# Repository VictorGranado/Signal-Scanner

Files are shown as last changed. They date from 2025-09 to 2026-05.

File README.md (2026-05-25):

# **Signal Scanner v1.0**

A multifunction handheld diagnostic and signal analysis tool for wireless scanning, RF detection, and basic electrical/electricmagnectic measurements.

---

## **Project Overview**

The **Signal Scanner v1.0** is a comprehensive diagnostic instrument built around the **ESP32-WROOM-DA** module.  
It combines **digital wireless analysis** (Wi-Fi, BLE, RF, EMF) with **electrical measurement capabilities** (Voltage, Current, Continuity, Frequency Counter) — all displayed through a dual-screen user interface.

Designed for **embedded developers, electronics hobbyists, and field engineers**, it provides a portable, menu-driven platform for analyzing and visualizing multiple signal domains in real time.

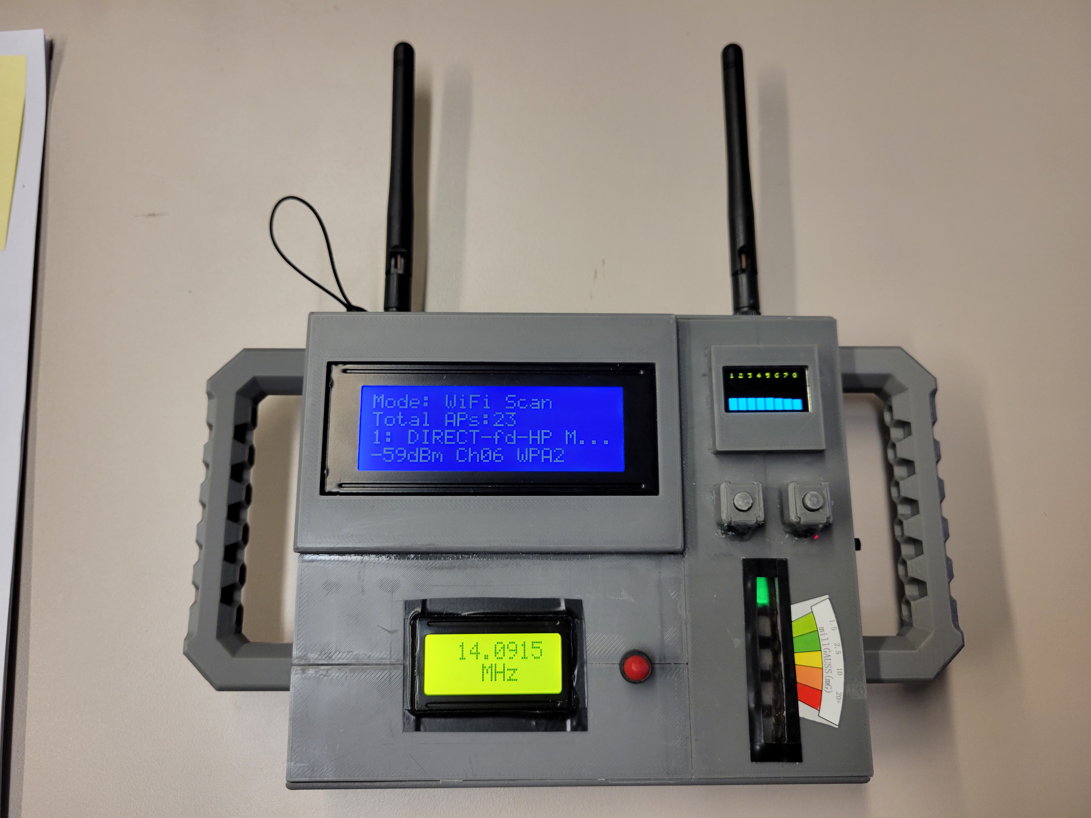
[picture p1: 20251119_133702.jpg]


---

## **Features**

### **1. Wi-Fi Scanner**
Scans for nearby wireless access points.  
**LCD:** displays SSID, RSSI (signal strength), channel, and encryption type.  
**OLED:** bar graph representation of the top RSSI values.

**Values:**
- **SSID:** network name  
- **RSSI:** signal strength in dBm (0 = strongest, −100 = weakest)  
- **CH:** Wi-Fi channel  
- **ENC:** encryption type (Open, WPA2, WPA3, etc.)

---

### **2. BLE Scanner**
Performs a passive BLE device scan using Kolban’s BLE library.  
**LCD:** shows device name (or MAC tail) and signal strength.  
**OLED:** bar graph of top device RSSI levels.

**Values:**
- **Device Name / MAC:** identifier  
- **RSSI (dBm):** received signal strength

---

### **3. Voltage Meter (0–25 V)**
Reads DC voltage via a voltage divider module and plots results on the OLED.  
**LCD:** shows wiring reference and live voltage reading.  
**OLED:** plots voltage (0–25 V) in real time.

**Connection:**
- **Probe+ → Voltage Divider Input**  
- **Probe− → GND**  
- **Divider output → GPIO34 (ADC1_CH6)**  

**Formula:**

Vin = Vadc × Divider Ratio

(Default: 5× module, optional 2× external divider)

---

### **4. Current Meter (ACS712-30A)**
Measures DC/AC current flow using the ACS712 Hall-effect sensor.  
**LCD:** shows wiring guide, live current, and plot status.  
**OLED:** real-time current graph (0–30 A scale).

**Connection:**
- **IP+ → Load supply input**  
- **IP− → Load output**  
- **Vout → ADC35 (ADC1_CH7)**  

**Calibration:**  
Long-press MODE in this mode to perform a **tare** (zero adjustment).

**Formula:**

I = (Vout - Voffset) / 0.066 (where 0.066 = 66 mV/A)

---

### **5. Continuity Tester**
Performs resistance-based continuity detection using a 10 kΩ pulldown reference.  
**LCD:** displays continuity status (“YES/NO”), resistance, and polarity note.  
**OLED:** shows an **animated connected wire** when continuity is detected or a **broken wire** when open.

**Connection:**
- **Red probe → GPIO25 (driven HIGH)**  
- **Black probe → GPIO32 (ADC1 input)**  
- **10 kΩ resistor → GPIO32 → GND**

**Logic:**

Rx = 10k × (3.3V - Vnode) / Vnode

Continuity = **YES** if Rx ≤ 600 Ω

---

### **6. RF Sniffer (AD8317)**
Measures relative RF power between 1 MHz–10 GHz using an AD8317 logarithmic detector.  
**LCD:** shows Vout voltage and equivalent dBm (calibrated or default).  
**OLED:** scrolling signal strength plot.

**Connection:**
- **AD8317 Vout → GPIO33 (ADC1_CH5)**  
- **Vcc:** 5 V  
- **GND:** common ground  
- **Antenna Input:** SMA connector (external antenna)

**Calibration:**
- **Long-press MODE** → capture P0 baseline (−90 dBm)  
- **Long-press SCROLL** → capture P1 reference (−30 dBm)

---

### **7. EMF Reader (Parallel)**
A parallel passive EMF detector monitors ambient electromagnetic activity.  
- Uses a **rectified antenna circuit** (antenna + diode + capacitor + amplifier).  
- Output is proportional to environmental EMF intensity.  
- **Display:** OLED bars or LED array (if connected).  

**Use Case:** detecting field sources (motors, transmitters, microwaves, etc.)

---

### **8. Frequency Counter (Parallel)**
Measures signal frequency via SMA or wired input.  
**LCD:** displays frequency in Hz/MHz.   
**Ideal for:** oscillators, PWM generators, communication signals.

**Connection:**
- **SMA Input:** strong RF or square-wave sources  
- **Wired Input:** logic-level test points  

---

## **Dynamic User Interface**

- **LCD (20×4)** — primary text interface: mode, wiring, and live values  
- **OLED (0.96″)** — graphical interface: signal bars, plots, or animation per mode  

**Controls:**
- **MODE (GPIO2):**  
  - Short press → change mode  
  - Long press (>1.2 s): special actions (tare, calibrate RF)
- **SCROLL (GPIO4):**  
  - Wi-Fi/BLE → scroll or auto-scroll lists  
  - Voltage/Current/RF → pause/resume plot  
  - RF → long press → capture calibration point

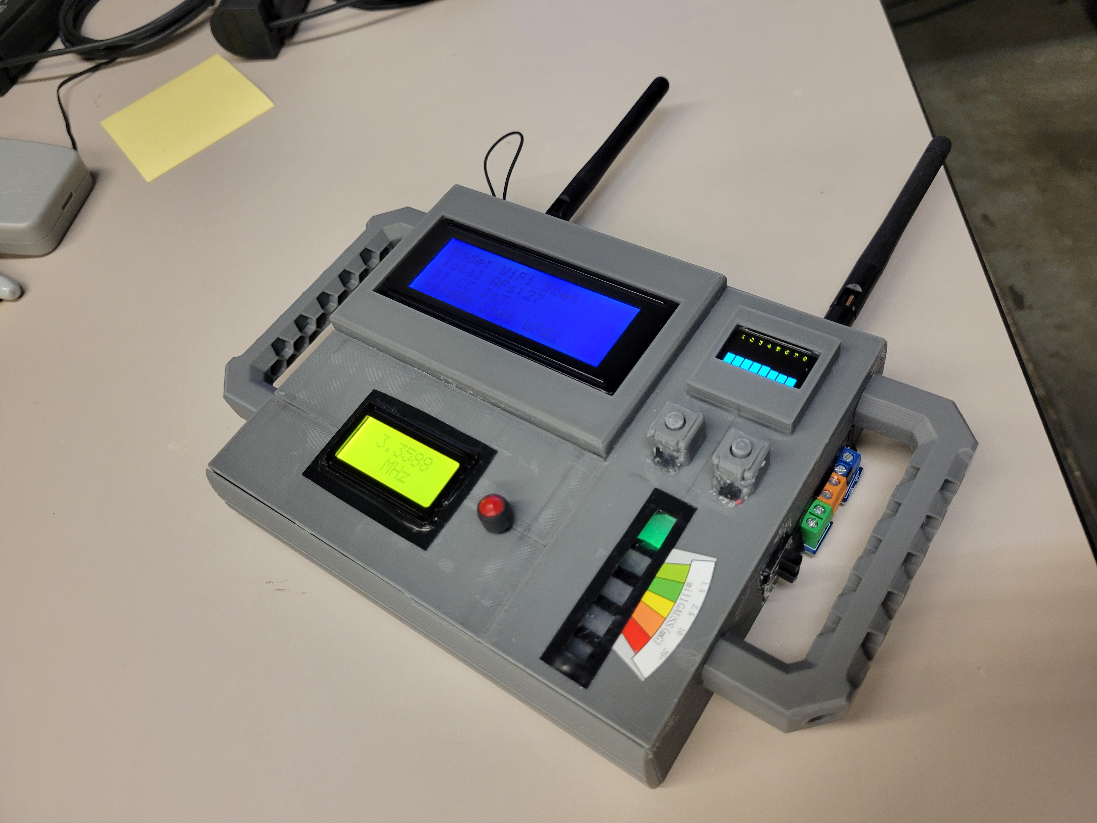
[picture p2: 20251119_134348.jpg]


---

## **System Specifications**

| Component | Function | Interface |
|---|---|---|
| ESP32-WROOM-DA | MCU + Wi-Fi + BLE + ADC | — |
| 20×4 LCD | Menu / Text | I²C (0x27) |
| 0.96″ OLED SSD1306 | Graphical plots | I²C (0x3C) |
| AD8317 | RF power detector (1 MHz–10 GHz) | Analog |
| ACS712-30A | Current sensing | Analog |
| Voltage Divider Module | Scales input to ADC range | Analog |
| Continuity Circuit | Resistance / continuity check | GPIO25 + ADC32 |
| EMF Detector | Field strength indication | Parallel |
| Frequency Counter | Pulse input (SMA / wired) | Parallel |
| Mode & Scroll Buttons | UI control | GPIO2, GPIO4 |
| Li-Ion Battery + Charger | Power source | — |

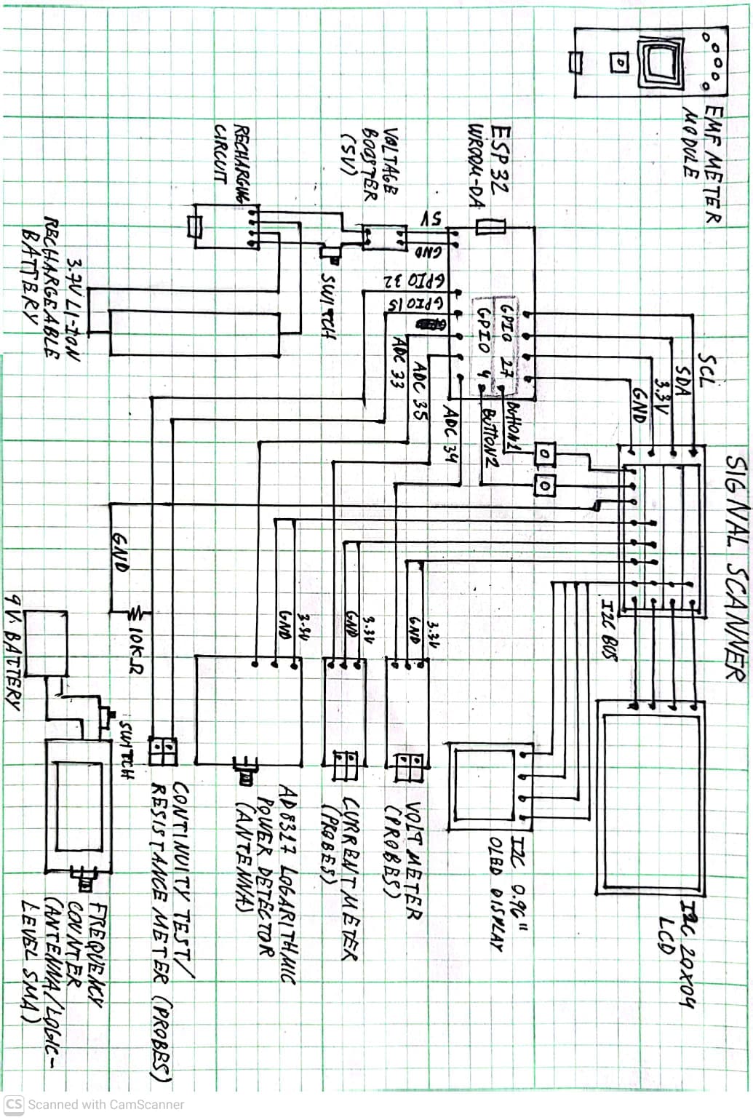
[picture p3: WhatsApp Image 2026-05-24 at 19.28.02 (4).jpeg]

---

## **Connection Configurations**

| Mode | Signal | ESP32 Pin | Notes |
|---|---|---|---|
| Voltage | Divider output | GPIO34 | Up to 25 V, 100k/100k divider |
| Current | ACS712 output | GPIO35 | 5 V module, 66 mV/A |
| Continuity | Probe+ = GPIO25, Probe− = GPIO32 | 10 kΩ pulldown to GND |
| RF Sniffer | AD8317 Vout | GPIO33 | 0.2–1.8 V typical |
| EMF Reader | Parallel analog | - | Relative measurement |
| Frequency Counter | SMA / wire input | - | Pulse input with limiter |

---

## **Setup and Usage**

1. Wire components according to the connection table.  
2. Install required Arduino libraries:  
   - `LiquidCrystal_I2C`  
   - `Adafruit_GFX`, `Adafruit_SSD1306`  
   - `WiFi`, `BLEDevice` (Kolban’s BLE)  
3. Open the main `.ino` file in Arduino IDE.  
4. Select **Partition Scheme → Huge APP**.  
5. Upload firmware to the ESP32.  
6. Power via USB or Li-Ion battery.  
7. Navigate using the MODE and SCROLL buttons.

---

## **Displayed Values and Their Meaning**

| Mode | Display Field | Meaning |
|---|---|---|
| Wi-Fi | SSID, RSSI, CH, ENC | Network information |
| BLE | Name/MAC, RSSI | Device info & signal strength |
| Voltage | Vin (V) | DC input voltage |
| Current | I (A) | Load current |
| Continuity | R (Ω), Continuity: YES/NO | Resistance or connection status |
| RF Sniffer | Vout (V), Power (dBm) | RF signal level |
| EMF | Bar level / LED | Field intensity |
| Frequency | f (Hz / MHz) | Signal frequency |

---

## **Test Plan and Results**

| Mode | Expected Behavior | Verified |
|---|---|---|
| Wi-Fi Scan | Detects SSIDs with correct RSSI and channels | ✅ |
| BLE Scan | Lists BLE devices with signal strength | ✅ |
| Voltage Meter | Reports accurate DC voltage after calibration | ✅ |
| Current Meter | Tare and dynamic response verified | ✅ |
| Continuity Tester | Detects shorts <600 Ω; OLED animation works | ✅ |
| RF Sniffer | Detects transmitters; relative dBm accurate | ✅ |
| EMF Reader | Responds to nearby EMF sources | ✅ |
| Frequency Counter | Stable frequency readings | ✅ |

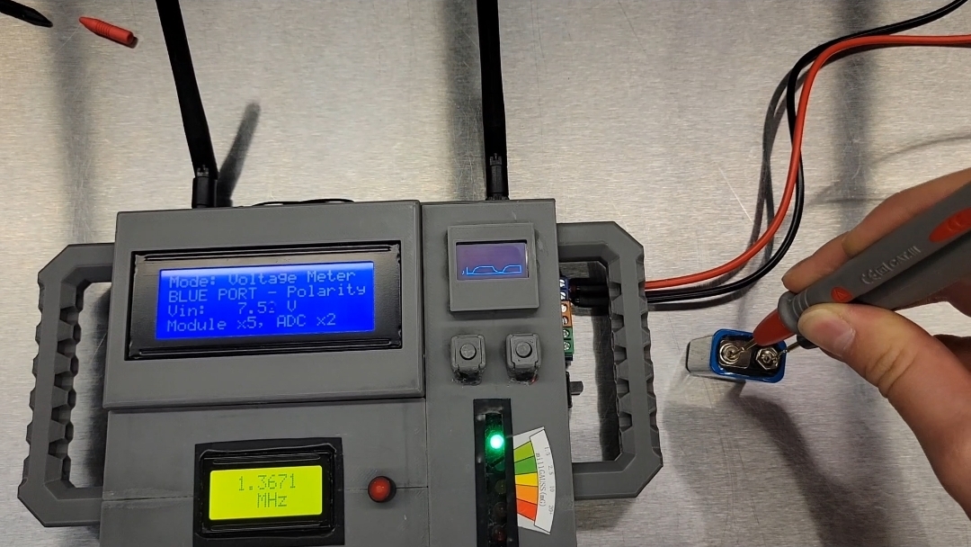
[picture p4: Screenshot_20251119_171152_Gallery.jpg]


---

## **Future Enhancements**

- SD card logging for data collection  
- Automatic range adjustment  
- RF sweep analyzer capability   

---

## **Updated Parts List**

| Component | Approx. Cost |
|---|---|
| ESP32-WROOM-DA | $5–10 |
| AD8317 RF Detector | $15–20 |
| ACS712-30A | $3–5 |
| Voltage Divider Module | $2–3 |
| Continuity Components | <$2 |
| EMF Detector Circuit | $14 |
| Frequency Counter (SMA Module) | $8–12 |
| 20×4 LCD | $5–10 |
| 0.96″ OLED SSD1306 | $2–5 |
| Buttons / Wiring | <$2 |
| Li-Ion Battery + Charger | $8–12 |
| **Total** | **~$70–100** |

---

## **Contributors**

**Victor Stafussi Granado** – Embedded Systems Design, Firmware Development, System Integration

---

## **License**

This project is licensed under the **MIT License**.  
See the LICENSE file for details.

---

## **Acknowledgments**

- AD8317 datasheet (Analog Devices)  
- ACS712, ESP32 ADC documentation  
- Arduino community libraries (Adafruit, Kolban, etc.)  
- EMF detector and frequency counter circuit references  
- Open-source hardware design resources

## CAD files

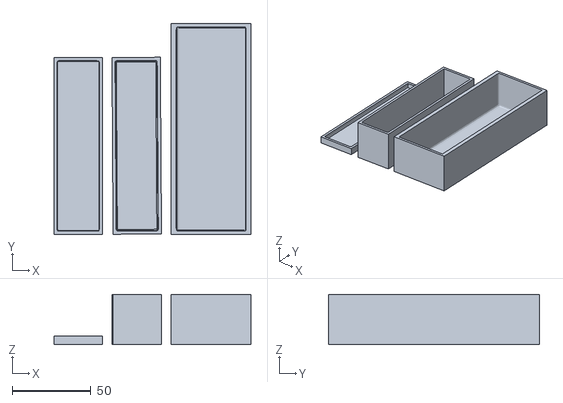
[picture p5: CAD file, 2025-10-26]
Signal Scanner disassembled part 3.stl
124.8 x 133.5 x 32.0

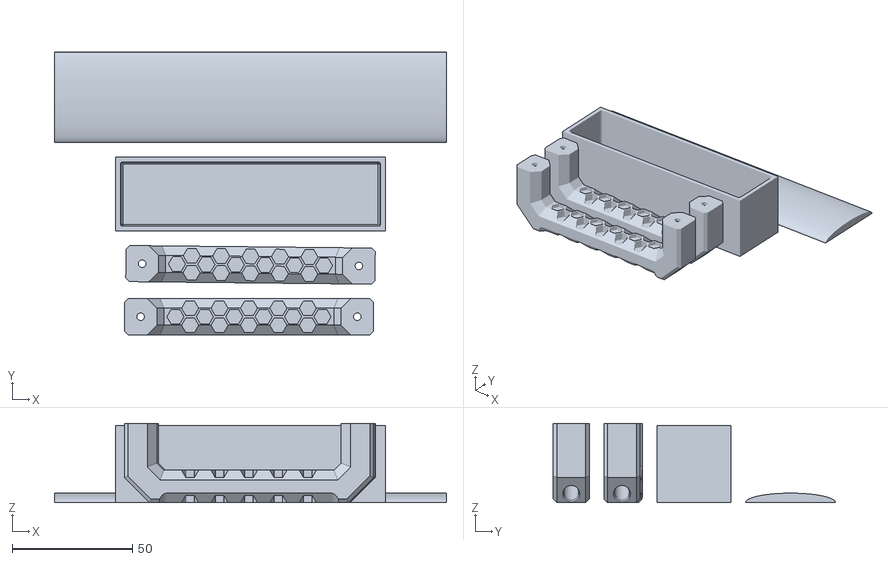
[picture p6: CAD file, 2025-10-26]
Signal Scanner disassembled part 4.stl
162.7 x 117.3 x 33.0

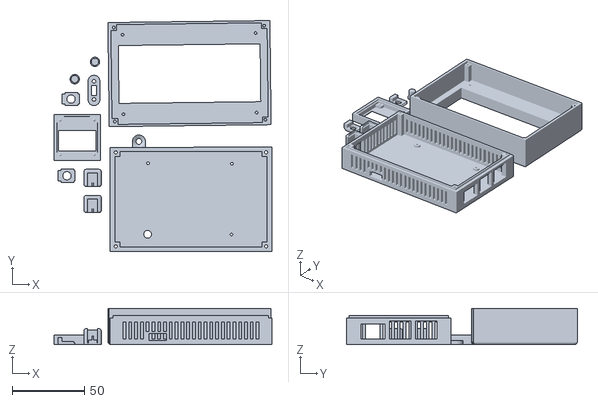
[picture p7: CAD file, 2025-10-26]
Signal Scanner disassembled part 1.stl
150.7 x 159.6 x 25.0

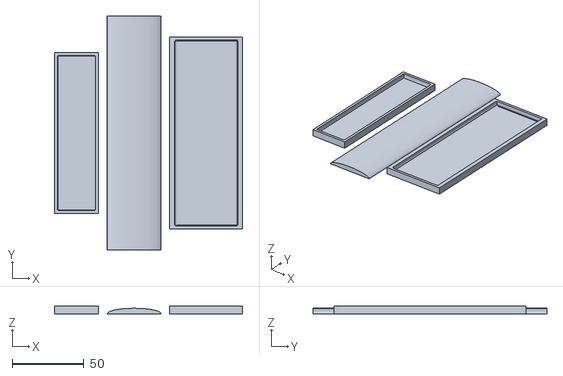
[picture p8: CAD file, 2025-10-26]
Signal Scanner disassembled part 2.stl
130.9 x 162.7 x 5.54

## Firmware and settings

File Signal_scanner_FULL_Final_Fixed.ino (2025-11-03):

// ================== Signal Scanner (ESP32-WROOM-DA) ==================
// Modes: Wi-Fi Scan + BLE Scan + Voltage Meter + Current Meter + Continuity + RF Sniffer (AD8317)
// ---------------------------------------------------------------------
// Hardware
//  - Buttons: MODE=GPIO2, SCROLL=GPIO4  (INPUT_PULLUP, LOW=pressed)
//  - LCD 20x4 I2C @ 0x27 (LiquidCrystal_I2C compatible fork recommended)
//  - OLED SSD1306 128x64 I2C @ 0x3C
//
// Voltage module (kit B08BZKPSFY):
//  - 0–25V module outputs ~Vin/5 (≈5 V at 25 V) -> add extra 2:1 divider to ESP32 ADC
//  - OUT -> 100k -> ADC34; ADC34 -> 100k -> GND  (overall x10 scale from ADC to Vin)
//
// Current module (ACS712-30A):
//  - Power at 5V, GND common with ESP32
//  - Route current IP+ (from supply) -> sensor -> IP- (to load)
//  - Vout -> 2:1 divider -> ADC35 (same 100k/100k idea)
//  - Sensitivity ≈ 66 mV/A, nominal mid ≈ 2.5 V at 0 A
//
// RF Sniffer (AD8317):
//  - Vout (0.2–1.8V typ) -> ADC33 (no divider)
//  - GND common, Vcc per module (~5V), antenna/probe on RF input
//
// Continuity (Option A):
//  - CONT_OUT=GPIO25 -> probe+, CONT_IN=GPIO26 -> probe- (ADC1), 10k pulldown to GND on CONT_IN
//
// Controls
//  - MODE (GPIO2):
//      * Short press: CHANGE MODE (WiFi → BLE → Volt → Curr → Cont → RF → …)
//      * Long press (>1.2s): in Current mode ONLY -> TARE (zero)
//      * Extra in RF mode: long press -> capture P0 baseline (-90 dBm)
//  - SCROLL (GPIO4):
//      * Wi-Fi/BLE: scroll list (hold to auto-scroll)
//      * Volt/Current/RF: pause/resume plot
//      * Extra in RF mode: long press -> capture P1 reference (-30 dBm)
//
// Splash:
//  - LCD: "Hello user", "Welcome to the Signal Scanner V1.0", "Initializing..."
//  - OLED: antenna with concentric waves animation
// ---------------------------------------------------------------------

#include <Arduino.h>
#include <Wire.h>
#include <LiquidCrystal_I2C.h>
#include <Adafruit_GFX.h>
#include <Adafruit_SSD1306.h>
#include <WiFi.h>

// BLE (Kolban)
#include <BLEDevice.h>
#include <BLEUtils.h>
#include <BLEScan.h>
#include <BLEAdvertisedDevice.h>

#include <vector>
#include <algorithm>
#include <math.h>

// ================= Pins =================
#define MODE_BUTTON_PIN    27
#define SCROLL_BUTTON_PIN  4
#define PIN_V_ADC          34    // ADC1_CH6 (Voltage)
#define PIN_I_ADC          35    // ADC1_CH7 (Current)
#define PIN_RF_ADC         33    // ADC1_CH5 (RF Vout)

// Continuity pins (Option A)
#define CONT_OUT           25    // drives 3.3V (probe +)
#define CONT_IN            32    // senses via ADC2_CH9 (probe -), external 10k pulldown to GND

// ================= LCD ==================
#define LCD_ADDR 0x27
#define LCD_COLS 20
#define LCD_ROWS 4
LiquidCrystal_I2C lcd(LCD_ADDR, LCD_COLS, LCD_ROWS);

// ================= OLED =================
#define OLED_RESET   -1
#define SCREEN_WIDTH 128
#define SCREEN_HEIGHT 64
Adafruit_SSD1306 oled(SCREEN_WIDTH, SCREEN_HEIGHT, &Wire, OLED_RESET);

// ================= Helpers =================
static String padOrTrim20(const String& s) {
  if (s.length() == 20) return s;
  if (s.length() < 20) { String t=s; while(t.length()<20) t+=' '; return t; }
  return s.substring(0,17) + "...";
}

static bool buttonEdge(uint8_t pin) {
  static uint32_t lastT[48] = {0};
  static uint8_t  lastS[48] = {HIGH};
  uint32_t now = millis();
  uint8_t s = digitalRead(pin);
  if (s != lastS[pin] && (now - lastT[pin]) > 30) {
    lastT[pin] = now;
    lastS[pin] = s;
    return (s == LOW);
  }
  return false;
}

static bool buttonHeld(uint8_t pin, uint32_t ms) {
  static uint32_t tDown[48] = {0};
  static uint8_t  wasDown[48] = {0};
  uint8_t s = (digitalRead(pin) == LOW);
  uint32_t now = millis();
  if (s && !wasDown[pin]) { wasDown[pin]=1; tDown[pin]=now; }
  else if (!s) { wasDown[pin]=0; return false; }
  if (wasDown[pin] && (now - tDown[pin] >= ms)) { return true; }
  return false;
}

// ================= Mode enum (use uint8_t to avoid proto issues) =================
enum ModeVals : uint8_t { WIFI_MODE=0, BLE_MODE, VOLT_MODE, CURR_MODE, CONT_MODE, RF_MODE, MODE_COUNT };
uint8_t currentMode = WIFI_MODE;

// forward declare
static void enterMode(uint8_t m);

// ===================== Wi-Fi Scanner =====================
struct APInfo { String ssid; int32_t rssi; int32_t channel; wifi_auth_mode_t enc; };
std::vector<APInfo> wifiAPs;
uint8_t wifiPage = 0;
uint32_t wifiHoldStart = 0, wifiLastScroll = 0;
const uint32_t scrollHoldTime = 500, scrollInterval = 500;

static const char* encToStr(wifi_auth_mode_t m) {
  switch (m) {
    case WIFI_AUTH_OPEN: return "OPEN";
    case WIFI_AUTH_WEP: return "WEP";
    case WIFI_AUTH_WPA_PSK: return "WPA";
    case WIFI_AUTH_WPA2_PSK: return "WPA2";
    case WIFI_AUTH_WPA_WPA2_PSK: return "WPA/WPA2";
    case WIFI_AUTH_WPA2_ENTERPRISE: return "WPA2-E";
    case WIFI_AUTH_WPA3_PSK: return "WPA3";
    case WIFI_AUTH_WPA2_WPA3_PSK: return "WPA2/3";
    default: return "?";
  }
}

static void oledBarsFromRSSI(const int *vals, int n, int nShow) {
  oled.clearDisplay(); oled.setTextSize(1); oled.setTextColor(SSD1306_WHITE);
  nShow = min(nShow, n);
  if (nShow <= 0) { oled.display(); return; }
  int w = SCREEN_WIDTH / nShow;
  int usableHeight = SCREEN_HEIGHT - 14;
  for (int i = 0; i < nShow; ++i) {
    int rssi = vals[i];
    rssi = max(-100, min(0, rssi));
    int bar = map(rssi, -100, 0, 0, usableHeight);
    int x = i * w;
    oled.setCursor(x + (w/2) - 3, 0); oled.print(i+1);
    oled.fillRect(x+1, SCREEN_HEIGHT - bar - 1, w - 3, bar, SSD1306_WHITE);
  }
  oled.display();
}

static void renderWiFiLCD(size_t idx) {
  lcd.setCursor(0,0); lcd.print(padOrTrim20("Mode: WiFi Scan"));
  char buf[21]; snprintf(buf,sizeof(buf),"Total APs:%-9d",(int)wifiAPs.size());
  lcd.setCursor(0,1); lcd.print(padOrTrim20(String(buf)));
  if (wifiAPs.empty()) {
    lcd.setCursor(0,2); lcd.print(padOrTrim20("No networks found"));
    lcd.setCursor(0,3); lcd.print(padOrTrim20(""));
    return;
  }
  const APInfo &a = wifiAPs[idx];
  String s1 = String(idx+1) + ": " + (a.ssid.length()?a.ssid:String("<hidden>"));
  lcd.setCursor(0,2); lcd.print(padOrTrim20(s1));
  snprintf(buf,sizeof(buf),"%ddBm Ch%02ld %s",(int)a.rssi,(long)a.channel,encToStr(a.enc));
  lcd.setCursor(0,3); lcd.print(padOrTrim20(String(buf)));
}

static void wifiScan() {
  lcd.clear(); renderWiFiLCD(0);
  WiFi.mode(WIFI_MODE_STA);
  WiFi.disconnect(true,true);
  delay(120);
  int n = WiFi.scanNetworks(false, true, false, 120);
  wifiAPs.clear();
  if (n > 0) {
    wifiAPs.reserve(n);
    for (int i=0;i<n;++i) {
      APInfo a; a.ssid=WiFi.SSID(i); a.rssi=WiFi.RSSI(i); a.channel=WiFi.channel(i); a.enc=WiFi.encryptionType(i);
      wifiAPs.push_back(a);
    }
    std::sort(wifiAPs.begin(), wifiAPs.end(), [](const APInfo&A,const APInfo&B){return A.rssi>B.rssi;});
    wifiPage=0; wifiHoldStart=wifiLastScroll=0;
  }
  renderWiFiLCD(wifiPage);
  const int maxBars = 8;
  int vals[maxBars]; int cnt = min((int)wifiAPs.size(), maxBars);
  for(int i=0;i<cnt;++i) vals[i]=wifiAPs[i].rssi;
  oledBarsFromRSSI(vals, cnt, cnt);
}

// ===================== BLE Scanner =====================
struct DevInfo { String name; String addr; int rssi; };
std::vector<DevInfo> bleDevs;
uint8_t blePage = 0;
uint32_t bleHoldStart = 0, bleLastScroll = 0;

int bleScanTime = 6;
BLEScan* pBLEScan = nullptr;

static String tailMac(const String& mac) {
  if (mac.length() >= 5) return mac.substring(mac.length()-5);
  return mac;
}

static void renderBLELCD(size_t idx) {
  lcd.setCursor(0,0); lcd.print(padOrTrim20("Mode: BLE Scan"));
  char buf[21]; snprintf(buf,sizeof(buf),"Total Dev:%-8d",(int)bleDevs.size());
  lcd.setCursor(0,1); lcd.print(padOrTrim20(String(buf)));
  if (bleDevs.empty()) {
    lcd.setCursor(0,2); lcd.print(padOrTrim20("No devices found"));
    lcd.setCursor(0,3); lcd.print(padOrTrim20(""));
    return;
  }
  const DevInfo &d = bleDevs[idx];
  String nm = d.name.length()? d.name : String("<noname>");
  String s1 = String(idx+1) + ": " + nm;
  lcd.setCursor(0,2); lcd.print(padOrTrim20(s1));
  snprintf(buf,sizeof(buf),"%ddBm %s",(int)d.rssi, tailMac(d.addr).c_str());
  lcd.setCursor(0,3); lcd.print(padOrTrim20(String(buf)));
}

static void oledBarsFromRSSI_BLE(const int *vals, int n, int nShow) {
  oled.clearDisplay(); oled.setTextSize(1); oled.setTextColor(SSD1306_WHITE);
  nShow = min(nShow, n);
  if (nShow <= 0) { oled.display(); return; }
  int w = SCREEN_WIDTH / nShow;
  int usableHeight = SCREEN_HEIGHT - 14;
  for (int i = 0; i < nShow; ++i) {
    int rssi = vals[i];
    rssi = max(-100, min(0, rssi));
    int bar = map(rssi, -100, 0, 0, usableHeight);
    int x = i * w;
    oled.setCursor(x + (w/2) - 3, 0); oled.print(i+1);
    oled.fillRect(x+1, SCREEN_HEIGHT - bar - 1, w - 3, bar, SSD1306_WHITE);
  }
  oled.display();
}

class MyAdvertisedDeviceCallbacks : public BLEAdvertisedDeviceCallbacks {
  void onResult(BLEAdvertisedDevice adv) override {
    DevInfo d;
    d.name = adv.haveName()? String(adv.getName().c_str()) : String("");
    d.addr = adv.getAddress().toString().c_str();
    d.rssi = adv.getRSSI();
    // upsert by MAC; keep strongest RSSI and latest name
    for (auto &x : bleDevs) {
      if (x.addr == d.addr) {
        if (d.rssi > x.rssi) x.rssi = d.rssi;
        if (d.name.length()) x.name = d.name;
        return;
      }
    }
    bleDevs.push_back(d);
  }
};

static void bleScan() {
  lcd.clear(); renderBLELCD(0);
  oled.clearDisplay(); oled.display();

  static bool inited=false;
  if (!inited) {
    BLEDevice::init("");
    pBLEScan = BLEDevice::getScan();
    pBLEScan->setAdvertisedDeviceCallbacks(new MyAdvertisedDeviceCallbacks(), true);
    pBLEScan->setActiveScan(true);
    pBLEScan->setInterval(100);
    pBLEScan->setWindow(99);
    inited = true;
  }
  bleDevs.clear();
  BLEScanResults* res = pBLEScan->start(bleScanTime, false);
  (void)res;
  std::sort(bleDevs.begin(), bleDevs.end(), [](const DevInfo&A,const DevInfo&B){return A.rssi>B.rssi;});
  blePage=0; bleHoldStart=bleLastScroll=0;
  renderBLELCD(blePage);
  const int maxBars=8; int vals[maxBars]; int cnt=min((int)bleDevs.size(), maxBars);
  for(int i=0;i<cnt;++i) vals[i]=bleDevs[i].rssi;
  oledBarsFromRSSI_BLE(vals, cnt, cnt);
  pBLEScan->clearResults();
}

// ===================== Voltage Meter =====================
static const float VREF_ADC        = 3.30f;   // with 11dB attenuation
static const float MODULE_RATIO    = 5.0f;    // 0–25V module: Vout ≈ Vin/5
static const float EXTRA_DIV       = 1.0f;    // set 2.0f if using extra 2:1 divider
static const float ADC_TO_VIN      = MODULE_RATIO * EXTRA_DIV; // overall scale
static const float V_FULL_SCALE    = 25.0f;   // plot top

static const int   ADC_SAMPLES_V   = 32;
static const float EMA_ALPHA_V     = 0.2f;
static float vTrace[SCREEN_WIDTH];
static bool  vPlotPaused = false;
static float emaV = 0.0f;

// ---- Two-point calibration (from your Fluke comparison) ----
// Vin_calibrated = CAL_GAIN_V * Vin_raw + CAL_OFFSET_V
static const float CAL_GAIN_V    = 1.032303f;
static const float CAL_OFFSET_V  = 0.470927f;   // volts


static int readADCavg(int pin, int n) { uint32_t acc=0; for(int i=0;i<n;++i) acc+=analogRead(pin); return (int)(acc/n); }
static float adcToVolts(int raw) { return (raw/4095.0f)*VREF_ADC; }

/*static float readVin() {
  int raw = readADCavg(PIN_V_ADC, ADC_SAMPLES_V);
  float vAdc = adcToVolts(raw);
  float vin  = vAdc * ADC_TO_VIN;
  if (vin < 0) vin = 0;
  return vin;
}*/

// Replace your readVin() with this calibrated version
static float readVin() {
  // Read averaged raw ADC and convert to volts at the ADC pin
  int   raw  = readADCavg(PIN_V_ADC, ADC_SAMPLES_V);
  float vAdc = adcToVolts(raw);          // volts at ADC pin (after any front-end divider)
  
  // Scale up by your divider/module ratio to get Vin (raw, uncalibrated)
  float vin_raw = vAdc * ADC_TO_VIN;

  // Apply 2-point calibration
  float vin_cal = (CAL_GAIN_V * vin_raw) + CAL_OFFSET_V;

  // Housekeeping
  if (vin_cal < 0)        vin_cal = 0;
  if (vin_cal > V_FULL_SCALE) vin_cal = V_FULL_SCALE;  // optional clamp for the plot

  return vin_cal;
}

//------------------------------------------------------------------------------------------------------------------------------------------------------

static void drawAxesVolt() {
  oled.clearDisplay(); oled.setTextColor(SSD1306_WHITE);
  const int gx=10, gy=6; const int gw=SCREEN_WIDTH-gx-2, gh=SCREEN_HEIGHT-gy-8;
  oled.drawRect(gx, gy, gw, gh, SSD1306_WHITE);
  oled.setTextSize(1);
  oled.setCursor(gx-22, gy-1); oled.print((int)V_FULL_SCALE); oled.print("V");
  oled.setCursor(gx-18, gy+gh-8); oled.print("0V");
  oled.display();
}

//-----------------------------------------------------------------------------------------------------------------------------------------------------
static void plotAddV(float v) { for(int i=0;i<SCREEN_WIDTH-1;++i) vTrace[i]=vTrace[i+1]; vTrace[SCREEN_WIDTH-1]=v; }

static void renderPlotV() {
  const int gx=10, gy=6; const int gw=SCREEN_WIDTH-gx-2, gh=SCREEN_HEIGHT-gy-8;
  oled.fillRect(gx+1, gy+1, gw-2, gh-2, SSD1306_BLACK);
  auto yFromV=[&](float v){ if(v<0)v=0; if(v>V_FULL_SCALE)v=V_FULL_SCALE;
    int y= gy+gh-2 - (int)round((v/V_FULL_SCALE)*(gh-3));
    if(y<gy+1)y=gy+1; if(y>gy+gh-2)y=gy+gh-2; return y; };
  int x0=gx+1, x1=gx+gw-2; int bufStart=SCREEN_WIDTH-(gw-2); if(bufStart<1) bufStart=1;
  int prevY=yFromV(vTrace[bufStart-1]);
  for(int x=x0; x<=x1; ++x){
    int idx=(x-x0)+bufStart; int y=yFromV(vTrace[idx]);
    oled.drawLine(x-1,prevY,x,y,SSD1306_WHITE); prevY=y;
  }
  oled.display();
}

static void renderLCDVolt(float vin) {
  lcd.setCursor(0,0); lcd.print(padOrTrim20("Mode: Voltage Meter"));
  lcd.setCursor(0,1); lcd.print(padOrTrim20("BLUE PORT - Polarity"));
  char buf[21]; snprintf(buf,sizeof(buf),"Vin: %6.2f V", vin);
  lcd.setCursor(0,2); lcd.print(padOrTrim20(String(buf)));
  String s4 = vPlotPaused ? String("Module x5, [PAUSE]") : String("Module x5, ADC x2 ");
  lcd.setCursor(0,3); lcd.print(padOrTrim20(s4));
}

// ===================== Current Meter (ACS712-30A) =====================
static const float DIV_RATIO_I     = 2.0f;     // 2:1 divider on ACS output
static const float ACS_VCC         = 5.00f;
static const float SENS_V_PER_A    = 0.066f;   // 66 mV/A
static const float I_FULL_SCALE    = 30.0f;

static const int   ADC_SAMPLES_I   = 32;
static const float EMA_ALPHA_I     = 0.2f;
static float iTrace[SCREEN_WIDTH];
static bool  iPlotPaused = false;
static float emaI = 0.0f;
static float tareZero_V = ACS_VCC*0.5f; // ~2.5 V nominal mid (sensor domain)

static float adcToSensorV_I(int raw) { float vAdc=adcToVolts(raw); return vAdc*DIV_RATIO_I; }
static float sensorVToAmps(float vSensor) { return (vSensor - tareZero_V) / SENS_V_PER_A; }

static void drawAxesCurr() {
  oled.clearDisplay(); oled.setTextColor(SSD1306_WHITE);
  const int gx=10, gy=6; const int gw=SCREEN_WIDTH-gx-2, gh=SCREEN_HEIGHT-gy-8;
  oled.drawRect(gx, gy, gw, gh, SSD1306_WHITE);
  oled.setTextSize(1);
  oled.setCursor(gx-22, gy-1);     oled.print((int)I_FULL_SCALE); oled.print("A");
  oled.setCursor(gx-16, gy+gh-8);  oled.print("0");
  oled.display();
}

static void plotAddI(float aAbs){ for(int i=0;i<SCREEN_WIDTH-1;++i) iTrace[i]=iTrace[i+1]; iTrace[SCREEN_WIDTH-1]=aAbs; }

static void renderPlotI(){
  const int gx=10, gy=6; const int gw=SCREEN_WIDTH-gx-2, gh=SCREEN_HEIGHT-gy-8;
  oled.fillRect(gx+1, gy+1, gw-2, gh-2, SSD1306_BLACK);
  auto yFromA=[&](float a){ if(a<0)a=0; if(a>I_FULL_SCALE)a=I_FULL_SCALE;
    int y= gy+gh-2 - (int)round((a/I_FULL_SCALE)*(gh-3));
    if(y<gy+1)y=gy+1; if(y>gy+gh-2)y=gy+gh-2; return y; };
  int x0=gx+1, x1=gx+gw-2; int bufStart=SCREEN_WIDTH-(gw-2); if(bufStart<1) bufStart=1;
  int prevY=yFromA(iTrace[bufStart-1]);
  for(int x=x0;x<=x1;++x){ int idx=(x-x0)+bufStart; int y=yFromA(iTrace[idx]);
    oled.drawLine(x-1,prevY,x,y,SSD1306_WHITE); prevY=y; }
  oled.display();
}

static void renderLCDCurr(float amps) {
  lcd.setCursor(0,0); lcd.print(padOrTrim20("Mode: Current Meter"));
  lcd.setCursor(0,1); lcd.print(padOrTrim20("GREEN PORT"));
  char buf[21]; snprintf(buf,sizeof(buf),"I: %7.3f A", amps);
  lcd.setCursor(0,2); lcd.print(padOrTrim20(String(buf)));
  String s4 = iPlotPaused ? String("Plot: [PAUSE]       ") : String("Plot: RUN           ");
  lcd.setCursor(0,3); lcd.print(padOrTrim20(s4));
}

// ===================== RF Sniffer (AD8317) =====================
static const int   ADC_SAMPLES_RF  = 64;
static const float EMA_ALPHA_RF    = 0.18f;

static const float DEFAULT_SLOPE_MV_PER_DB = 22.0f;    // ~22 mV/dB
static const float DEFAULT_REF_DBM         = -30.0f;
static const float DEFAULT_REF_VOLT        = 1.10f;

static float rfTrace[SCREEN_WIDTH];
static bool  rfPlotPaused = false;
static float emaVrf = 0.0f, emaDBrf = -100.0f;

static float cal_a = -1000.0f / DEFAULT_SLOPE_MV_PER_DB;   // ≈ -45.45 dB/V
static float cal_b = DEFAULT_REF_DBM - cal_a * DEFAULT_REF_VOLT;

static bool  haveP0=false, haveP1=false;
static float P0_V=0, P0_dBm=-90.0f;
static float P1_V=0, P1_dBm=-30.0f;

static void rfRecomputeAB() {
  if (haveP0 && haveP1 && fabsf(P1_V - P0_V) > 0.02f) {
    cal_a = (P1_dBm - P0_dBm) / (P1_V - P0_V);
    cal_b = P0_dBm - cal_a * P0_V;
  }
}

static float voltsToDbm(float v) {
  float d = cal_a * v + cal_b;
  if (d < -100.0f) d = -100.0f;
  if (d >   0.0f) d =   0.0f;
  return d;
}

static void drawAxesRF() {
  oled.clearDisplay(); oled.setTextColor(SSD1306_WHITE);
  const int gx=10, gy=6; const int gw=SCREEN_WIDTH-gx-2, gh=SCREEN_HEIGHT-gy-8;
  oled.drawRect(gx, gy, gw, gh, SSD1306_WHITE);
  oled.setTextSize(1);
  oled.setCursor(0, gy-1);     oled.print("0");
  oled.setCursor(0, gy+gh-8);  oled.print("100");
  oled.display();
}

static void rfPlotAdd(float dBm) { for(int i=0;i<SCREEN_WIDTH-1;++i) rfTrace[i]=rfTrace[i+1]; rfTrace[SCREEN_WIDTH-1]=dBm; }
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
void loop() {
  // ---- MODE (GPIO2): long press = TARE in Current / capture P0 in RF; short press = CHANGE MODE ----
  if (buttonHeld(MODE_BUTTON_PIN, 1200)) {
    if (currentMode == CURR_MODE) {
      int raw = readADCavg(PIN_I_ADC, 128);
      float vAdc = adcToVolts(raw);
      float vSens = vAdc * DIV_RATIO_I;
      tareZero_V = vSens;
      lcd.setCursor(0,3); lcd.print(padOrTrim20("Tare: zero captured"));
      delay(300);
    } else if (currentMode == RF_MODE) {
      int raw = readADCavg(PIN_RF_ADC, 200);
      float v = adcToVolts(raw);
      P0_V = v; P0_dBm = -90.0f; haveP0 = true; rfRecomputeAB();
      lcd.setCursor(0,3); lcd.print(padOrTrim20("RF: P0 = -90 dBm   "));
      delay(300);
    }
  } else if (buttonEdge(MODE_BUTTON_PIN)) {
    // CHANGE MODE on short press
    currentMode = (uint8_t)((currentMode + 1) % MODE_COUNT);
    enterMode(currentMode);
    delay(150);
  }

  // ---- SCROLL (GPIO4) ----
  if (currentMode==WIFI_MODE) {
    if (digitalRead(SCROLL_BUTTON_PIN)==LOW) {
      if (!wifiHoldStart) {
        wifiHoldStart=millis();
        if (!wifiAPs.empty()) { wifiPage=(wifiPage+1)%wifiAPs.size(); renderWiFiLCD(wifiPage); }
      } else if (millis()-wifiHoldStart>scrollHoldTime && millis()-wifiLastScroll>scrollInterval) {
        if (!wifiAPs.empty()) { wifiPage=(wifiPage+1)%wifiAPs.size(); renderWiFiLCD(wifiPage); }
        wifiLastScroll=millis();
      }
    } else { wifiHoldStart=wifiLastScroll=0; }

  } else if (currentMode==BLE_MODE) {
    if (digitalRead(SCROLL_BUTTON_PIN)==LOW) {
      if (!bleHoldStart) {
        bleHoldStart=millis();
        if (!bleDevs.empty()) { blePage=(blePage+1)%bleDevs.size(); renderBLELCD(blePage); }
      } else if (millis()-bleHoldStart>scrollHoldTime && millis()-bleLastScroll>scrollInterval) {
        if (!bleDevs.empty()) { blePage=(blePage+1)%bleDevs.size(); renderBLELCD(blePage); }
        bleLastScroll=millis();
      }
    } else { bleHoldStart=bleLastScroll=0; }

  } else if (currentMode==VOLT_MODE) {
    if (buttonEdge(SCROLL_BUTTON_PIN)) vPlotPaused = !vPlotPaused;

  } else if (currentMode==CURR_MODE) {
    if (buttonEdge(SCROLL_BUTTON_PIN)) iPlotPaused = !iPlotPaused;

  } else if (currentMode==RF_MODE) {
    // Short press: pause/resume; Long press: capture P1 reference (-30 dBm)
    if (buttonHeld(SCROLL_BUTTON_PIN, 1200)) {
      int raw = readADCavg(PIN_RF_ADC, 200);
      float v = adcToVolts(raw);
      P1_V = v; P1_dBm = -30.0f; haveP1 = true; rfRecomputeAB();
      lcd.setCursor(0,3); lcd.print(padOrTrim20("RF: P1 = -30 dBm   "));
      delay(300);
    } else if (buttonEdge(SCROLL_BUTTON_PIN)) {
      rfPlotPaused = !rfPlotPaused;
    }
  }

  // ---- Mode processing ----
  if (currentMode==VOLT_MODE) {
    float v = readVin();
    emaV = (EMA_ALPHA_V*v) + (1.0f-EMA_ALPHA_V)*emaV;
    renderLCDVolt(emaV);
    if (!vPlotPaused) plotAddV(emaV);
    renderPlotV();
    delay(50);

  } else if (currentMode==CURR_MODE) {
    int raw = readADCavg(PIN_I_ADC, ADC_SAMPLES_I);
    float vSens = adcToSensorV_I(raw);
    float amps = sensorVToAmps(vSens);
    emaI = (EMA_ALPHA_I*amps) + (1.0f-EMA_ALPHA_I)*emaI;
    renderLCDCurr(emaI);
    float aAbs = fabsf(emaI);
    if (!iPlotPaused) plotAddI(aAbs);
    renderPlotI();
    delay(50);

  } else if (currentMode==CONT_MODE) {
    doContinuity();      // EXACT logic from the working test
    delay(90);

  } else if (currentMode==RF_MODE) {
    int raw = readADCavg(PIN_RF_ADC, ADC_SAMPLES_RF);
    float v = adcToVolts(raw);
    emaVrf = (EMA_ALPHA_RF*v) + (1.0f-EMA_ALPHA_RF)*emaVrf;

    float dBm = voltsToDbm(emaVrf);
    emaDBrf = (EMA_ALPHA_RF*dBm) + (1.0f-EMA_ALPHA_RF)*emaDBrf;

    renderLCDRF(emaVrf, emaDBrf);
    if (!rfPlotPaused) rfPlotAdd(emaDBrf);
    renderPlotRF();
    delay(40);

  } else {
    delay(20);
  }
}

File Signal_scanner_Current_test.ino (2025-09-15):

// ====== ESP32 Current Meter for ACS712-30A (B08BZKPSFY) ======
// - LCD 20x4: mode, probe wiring, live current with sign
// - OLED 128x64: real-time plot of |I| from 0..30 A (no symbol)
// - MODE button (pin 2): Zero/Tare (set current offset)
// - SCROLL button (pin 4): Pause/Resume plot
//
// Wiring:
//   ACS712 @ 5V:  Vcc=5V, GND=GND
//   Current path in series: IP+ (from supply) -> sensor -> IP- (to load)
//   Sensor OUT -> 2:1 divider -> ESP32 ADC (GPIO39 recommended)
//     e.g., OUT --100k--+-- ADC39
//                        |
//                       100k
//                        |
//                       GND
//
// Notes:
//   ACS712-30A sensitivity ~ 66 mV/A @ 5V supply.
//   Vout = 2.5V + (66 mV/A)*I  (I positive for IP+ -> IP-).
//   After 2:1 divider, ADC sees ~ (Vout/2).
//   We'll tare the midpoint with MODE to cancel offset/drift.

#include <Arduino.h>
#include <Wire.h>
#include <LiquidCrystal_I2C.h>
#include <Adafruit_GFX.h>
#include <Adafruit_SSD1306.h>

// ---------- Pins ----------
#define MODE_BUTTON_PIN    2
#define SCROLL_BUTTON_PIN  4
#define PIN_I_ADC          34    // ADC1_CH3 (GPIO39)

// ---------- LCD ----------
#define LCD_ADDR 0x27
#define LCD_COLS 20
#define LCD_ROWS 4
LiquidCrystal_I2C lcd(LCD_ADDR, LCD_COLS, LCD_ROWS);

// ---------- OLED ----------
#define OLED_RESET   -1
#define SCREEN_WIDTH 128
#define SCREEN_HEIGHT 64
Adafruit_SSD1306 oled(SCREEN_WIDTH, SCREEN_HEIGHT, &Wire, OLED_RESET);

// ---------- ACS712 scaling ----------
static const float ESP_VREF          = 3.30f;   // ADC full-scale volts (11 dB)
static const float DIV_RATIO         = 2.0f;    // 2:1 divider from sensor Vout to ADC
static const float ACS_VCC           = 5.00f;   // ACS supply
static const float ACS_ZERO_V        = ACS_VCC * 0.5f;   // ~2.5 V mid
static const float SENS_mV_PER_A     = 66.0f;   // ACS712-30A sensitivity
static const float SENS_V_PER_A      = SENS_mV_PER_A / 1000.0f; // 0.066 V/A
static const float FULL_SCALE_A      = 30.0f;   // plot top (0..30A magnitude)

// Calibration trims
static const float GAIN_TRIM         = 1.000f;  // multiply current
static const float OFFSET_TRIM_A     = 0.000f;  // add/subtract amps after tare if needed

// Sampling / smoothing
static const int   ADC_SAMPLES       = 32;
static const float EMA_ALPHA         = 0.2f;

// Plot buffer & state
static float trace[SCREEN_WIDTH];
static bool  plotPaused = false;
static float emaI = 0.0f;

// Tare (zero) state (in Volts at the sensor output, pre-divider domain)
static float tareZero_V = ACS_ZERO_V;  // start at nominal 2.5V mid

// ---------- Helpers ----------
static bool buttonPressed(uint8_t pin) {
  static uint32_t lastT[40] = {0};
  static uint8_t  lastS[40] = {HIGH};
  uint32_t now = millis();
  uint8_t s = digitalRead(pin);
  if (s != lastS[pin] && (now - lastT[pin]) > 30) {
    lastT[pin] = now;
    lastS[pin] = s;
    if (s == LOW) return true;
  }
  return false;
}

static int readADCavg(int pin, int n) {
  uint32_t acc = 0;
  for (int i = 0; i < n; ++i) acc += analogRead(pin);
  return (int)(acc / n);
}
static float adcToVolts(int raw) { return (raw / 4095.0f) * ESP_VREF; }

// Convert ADC reading -> sensor output volts (undo divider)
static float adcToSensorV(int raw) {
  float vAdc = adcToVolts(raw);
  return vAdc * DIV_RATIO; // back to sensor-output domain
}

// Compute current (amps) from sensor output volts with tare & trims
static float sensorVToAmps(float vSensor) {
  float deltaV = vSensor - tareZero_V;       // remove offset (tare)
  float amps   = deltaV / SENS_V_PER_A;      // I = dV / (0.066 V/A)
  amps = amps * GAIN_TRIM + OFFSET_TRIM_A;
  return amps;
}

static String padOrTrim20(const String& s) {
  if (s.length() == 20) return s;
  if (s.length() < 20) { String t=s; while(t.length()<20) t+=' '; return t; }
  return s.substring(0,17) + "...";
}

// ---------- UI ----------
static void renderLCD(float amps) {
  lcd.setCursor(0,0); lcd.print(padOrTrim20("Mode: Current Meter"));
  // Wiring hint
  lcd.setCursor(0,1); lcd.print(padOrTrim20("IP+=SUP IP-=LOAD"));
  // Live current with sign
  char buf[21]; snprintf(buf, sizeof(buf), "I: %7.3f A", amps);
  lcd.setCursor(0,2); lcd.print(padOrTrim20(String(buf)));
  // State line
  String s4 = plotPaused ? String("Plot: [PAUSE]       ")
                         : String("Plot: RUN           ");
  lcd.setCursor(0,3); lcd.print(padOrTrim20(s4));
}

static void drawAxes() {
  oled.clearDisplay();
  oled.setTextColor(SSD1306_WHITE);
  const int gx=10, gy=6; const int gw=SCREEN_WIDTH-gx-2, gh=SCREEN_HEIGHT-gy-8;
  oled.drawRect(gx, gy, gw, gh, SSD1306_WHITE);
  oled.setTextSize(1);
  oled.setCursor(gx-22, gy-1);     oled.print((int)FULL_SCALE_A); oled.print("A");
  oled.setCursor(gx-16, gy+gh-8);  oled.print("0");
  oled.display();
}

static void plotAddPoint(float ampsAbs){
  for(int i=0;i<SCREEN_WIDTH-1;++i) trace[i]=trace[i+1];
  trace[SCREEN_WIDTH-1]=ampsAbs;
}

static void renderPlot(){
  const int gx=10, gy=6; const int gw=SCREEN_WIDTH-gx-2, gh=SCREEN_HEIGHT-gy-8;
  oled.fillRect(gx+1, gy+1, gw-2, gh-2, SSD1306_BLACK);
  auto yFromA = [&](float a){
    if(a<0) a=0; if(a>FULL_SCALE_A) a=FULL_SCALE_A;
    int y = gy+gh-2 - (int)round((a/FULL_SCALE_A)*(gh-3));
    if(y<gy+1) y=gy+1; if(y>gy+gh-2) y=gy+gh-2; return y;
  };
  int x0=gx+1, x1=gx+gw-2; int bufStart=SCREEN_WIDTH-(gw-2); if(bufStart<1) bufStart=1;
  int prevY=yFromA(trace[bufStart-1]);
  for(int x=x0; x<=x1; ++x){
    int idx=(x-x0)+bufStart; int y=yFromA(trace[idx]);
    oled.drawLine(x-1, prevY, x, y, SSD1306_WHITE);
    prevY=y;
  }
  oled.display();
}

// ---------- Setup/Loop ----------
void setup(){
  pinMode(MODE_BUTTON_PIN,INPUT_PULLUP);
  pinMode(SCROLL_BUTTON_PIN,INPUT_PULLUP);

  lcd.init(); lcd.backlight();
  Wire.begin();
  oled.begin(SSD1306_SWITCHCAPVCC,0x3C);
  oled.clearDisplay(); oled.display();

  analogReadResolution(12);
  analogSetPinAttenuation(PIN_I_ADC, ADC_11db); // up to ~3.3 V on ADC pin

  // Init plot buffer
  for(int i=0;i<SCREEN_WIDTH;++i) trace[i]=0.0f;
  drawAxes();

  Serial.begin(115200);
  delay(100);
}

void loop(){
  // MODE -> Tare (capture current zero point)
  if (buttonPressed(MODE_BUTTON_PIN)) {
    // Average a few samples to set tareZero_V
    int raw = readADCavg(PIN_I_ADC, 128);
    tareZero_V = adcToSensorV(raw);
  }

  // SCROLL -> Pause/Resume
  if (buttonPressed(SCROLL_BUTTON_PIN)) {
    plotPaused = !plotPaused;
  }

  // Measure current
  int raw = readADCavg(PIN_I_ADC, ADC_SAMPLES);
  float vSensor = adcToSensorV(raw);
  float amps    = sensorVToAmps(vSensor);

  // Smooth
  emaI = EMA_ALPHA*amps + (1.0f-EMA_ALPHA)*emaI;

  // Update LCD
  renderLCD(emaI);

  // Update plot with magnitude
  float aAbs = fabsf(emaI);
  if (!plotPaused) plotAddPoint(aAbs);
  renderPlot();

  // Debug (optional)
  // Serial.printf("raw=%d  vADC=%.3f  vSens=%.3f  I=%.3f A  tare=%.3f V\n",
  //               raw, adcToVolts(raw), vSensor, emaI, tareZero_V);

  delay(50);
}
